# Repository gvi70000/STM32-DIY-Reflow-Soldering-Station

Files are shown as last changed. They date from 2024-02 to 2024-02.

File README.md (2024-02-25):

# STM32-DIY-Reflow-Soldering-Station

Warning: Electrical Safety Notice

Before attempting to build or operate the DIY reflow soldering station described in this article, it is imperative to be aware that the hardware operates at 220V AC. Working with high-voltage systems poses inherent risks and demands a thorough understanding of electrical safety precautions.
Front
Back

Introduction:

For electronics enthusiasts seeking a precise and customizable reflow soldering experience, constructing a DIY reflow soldering station is an exciting project. This article provides a detailed overview of the key components and their functionalities, offering a comprehensive guide for building your own soldering station.

Power Supply:

The 220V AC is supplied through the AC Power Entry Module IEC-320 C-14 BVA01/Z0000/02. A Transformer Myrra 47152 steps down the voltage to a crucial 5V, supplying power to essential components such as the BluePill with STM32F302 microcontroller board, fan, and the G3MB-202P 5V DC 1 Channel Solid-State Relay.

PowerSocket
Relay
NTC
Myrra
LCD
Plate
PEC11R-4220F-S0024
EnclosureFront
EnclosureBack
InnerView

User Interface:

The station features a user-friendly interface displayed on a 1.8" ST7735 LCD. User inputs are facilitated through an encoder PEC11R-4220F-S0024 and an RS PRO 17mm Black Potentiometer Knob for 6mm Shaft with a D-shaped grip, ensuring precise control over the soldering process.
Temperature Control and Cooling:

Maintaining optimal temperature is achieved through two strategically positioned 100K ohm 3950 NTC's, calibrated with meticulous accuracy using an FLUKE 51 II Thermometer as a reference. The reflow soldering station incorporates a CFM-6020S-040-320 fan, intelligently activated to cool down the hot plate when needed, ensuring temperature stability.

Operational Modes:

The DIY reflow soldering station offers two distinct modes: rework and reflow. In rework mode, the temperature is kept at a preset value, allowing for precise touch-up soldering. In reflow mode, the temperature follows a preset profile, ideal for soldering components with specific temperature requirements. Both modes utilize a PID controller, ensuring consistent and accurate temperature control throughout the soldering process.

Connections:

The intricate network of connections ensures seamless communication and control within the system. Notable connections include those for SD Card, Encoder, ADC for NTCs, Fan control, Hot plate power control, Buzzer, Encoder button, LCD command, and SPI interface.
Conclusion:

Building your own DIY reflow soldering station offers the satisfaction of creating a precise and reliable tool tailored to your needs. With a robust power supply, intuitive user interface, accurate temperature control, and intelligent cooling, this reflow soldering station provides the necessary features for successful soldering projects. As you embark on this DIY journey, ensure meticulous attention to detail in the assembly and follow safety guidelines to enjoy a versatile and efficient soldering tool for your electronics projects.

The enclosure outline for LASER cutting from 4mm thick acrylic sheet can be downloaded here.

KiCAD Schematic and PCB for controller are available here.

The software for STM32F302 can be downloaded here.

Please note that the PID parameters are generic and you need to change them according to your system, the values are found in Reflow.h file

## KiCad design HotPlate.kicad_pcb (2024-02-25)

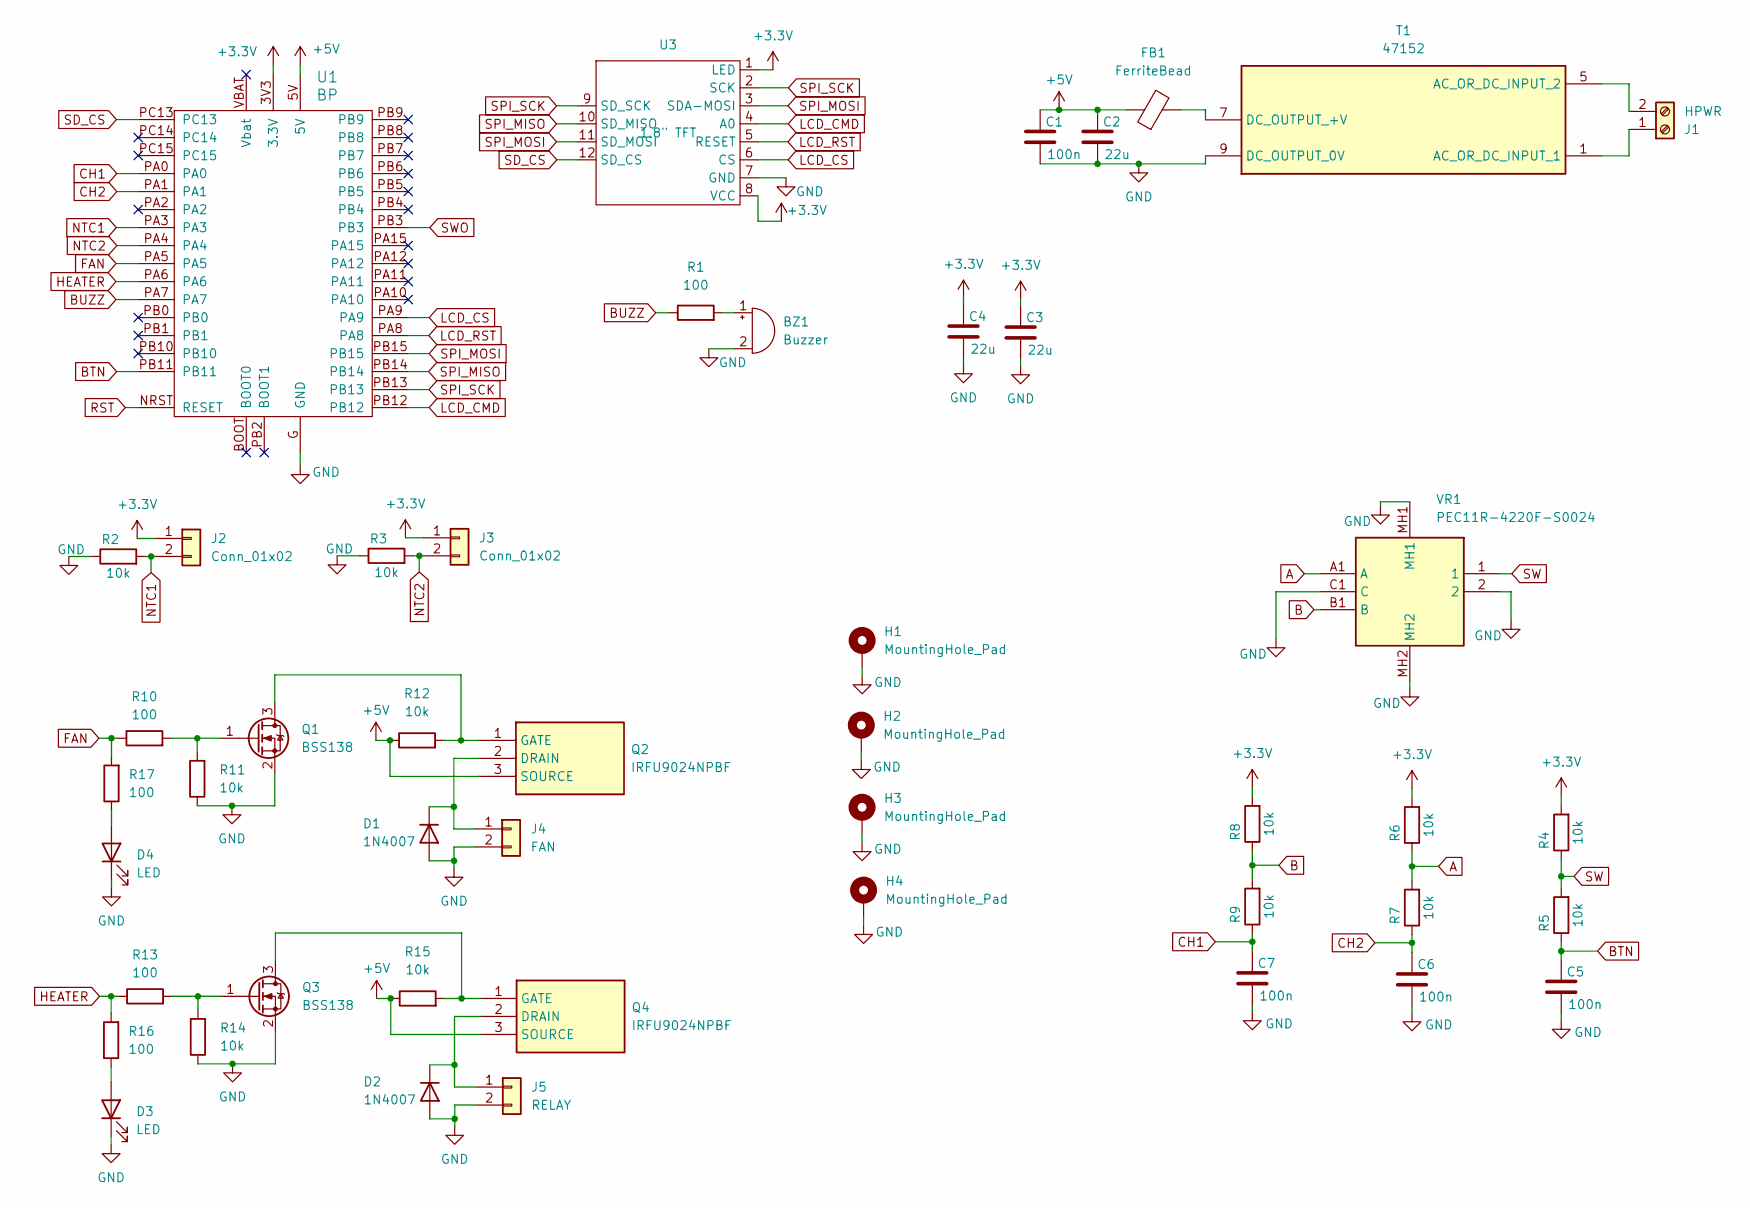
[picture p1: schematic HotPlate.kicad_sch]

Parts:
BZ1: Buzzer; Buzzer_TDK_PS1240P02BT_D12.2mm_H6.5mm
C1, C5, C6, C7: 100n; C_0805_2012Metric
C2, C3, C4: 22u; CP_EIA-7343-43_Kemet-X_Pad2.25x2.55mm_HandSolder
D1, D2: 1N4007; D_DO-41_SOD81_P10.16mm_Horizontal
D3, D4: LED; LED_D3.0mm
FB1: FerriteBead; R_0805_2012Metric
H1, H2, H3, H4: MountingHole_Pad; MountingHole_3.2mm_M3_Pad_Via
J1: HPWR; TerminalBlock_Phoenix_PT-1,5-2-5.0-H_1x02_P5.00mm_Horizontal
J2, J3: Conn_01x02; PinHeader_1x02_P2.54mm_Vertical
J4: FAN; PinHeader_1x02_P2.54mm_Vertical
J5: RELAY; PinHeader_1x02_P2.54mm_Vertical
Q1, Q3: BSS138; SOT-23
Q2, Q4: IRFU9024NPBF; TO-251-3_Vertical; Mouser Part Number 942-IRFU9024NPBF
R1: 100; R_0805_2012Metric_Pad1.20x1.40mm_HandSolder
R2, R3, R4, R5, R6, R7, R8, R9: 10k; R_0805_2012Metric_Pad1.20x1.40mm_HandSolder
R10, R13, R16, R17: 100; R_0805_2012Metric
R11, R12, R14, R15: 10k; R_0805_2012Metric
T1: 47152; MYRRA-47121; Manufacturer_Part_Number 47152
U1: BP; blue_pill
U3: 1.8" TFT; 1.8 TFT
VR1: PEC11R-4220F-S0024; PEC11R4220FS0024; Mouser Part Number 652-PEC11R-4220F-S24

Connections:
+3.3V: C3.1, C4.1, J2.1, J3.1, R4.2, R6.2, R8.2, U1.3V3 (3.3V), U3.1 (LED), U3.8 (VCC)
+5V: C1.1, C2.1, FB1.1, Q2.3 (SOURCE), Q4.3 (SOURCE), R12.1, R15.1, U1.5V
A: R6.1, R7.2, VR1.A1 (A)
B: R8.1, R9.2, VR1.B1 (B)
BTN: C5.1, R5.1, U1.PB11
BUZZ: R1.1, U1.PA7
CH1: C7.1, R9.1, U1.PA0
CH2: C6.1, R7.1, U1.PA1
FAN: R10.1, R17.2, U1.PA5
GND: BZ1.2 (+), C1.2, C2.2, C3.2, C4.2, C5.2, C6.2, C7.2, D1.2 (A), D2.2 (A), D3.1 (K), D4.1 (K), H1.1, H2.1, H3.1, H4.1, J4.2, J5.2, Q1.2 (S), Q3.2 (S), R2.1, R3.1, R11.1, R14.1, T1.9 (DC_OUTPUT_0V), U1.G (GND), U3.7 (GND), VR1.2, VR1.C1 (C), VR1.MH1, VR1.MH2
HEATER: R13.1, R16.2, U1.PA6
LCD_CMD: U1.PB12, U3.4 (A0)
LCD_CS: U1.PA9, U3.6 (CS)
LCD_RST: U1.PA8, U3.5 (RESET)
NTC1: J2.2, R2.2, U1.PA3
NTC2: J3.2, R3.2, U1.PA4
unnamed: BZ1.1 (-), R1.2
unnamed: D1.1 (K), J4.1, Q2.2 (DRAIN)
unnamed: D2.1 (K), J5.1, Q4.2 (DRAIN)
unnamed: D3.2 (A), R16.1
unnamed: D4.2 (A), R17.1
unnamed: J1.1, T1.1 (AC_OR_DC_INPUT_1)
unnamed: J1.2, T1.5 (AC_OR_DC_INPUT_2)
unnamed: Q1.3 (D), Q2.1 (GATE), R12.2
unnamed: Q1.1 (G), R10.2, R11.2
unnamed: Q3.3 (D), Q4.1 (GATE), R15.2
unnamed: Q3.1 (G), R13.2, R14.2
unnamed: FB1.2, T1.7 (DC_OUTPUT_+V)
RST: U1.NRST (RESET)
SD_CS: U1.PC13, U3.12 (SD_CS)
SPI_MISO: U1.PB14, U3.10 (SD_MISO)
SPI_MOSI: U1.PB15, U3.3 (SDA-MOSI), U3.11 (SD_MOSI)
SPI_SCK: U1.PB13, U3.2 (SCK), U3.9 (SD_SCK)
SW: R4.1, R5.2, VR1.1
SWO: U1.PB3

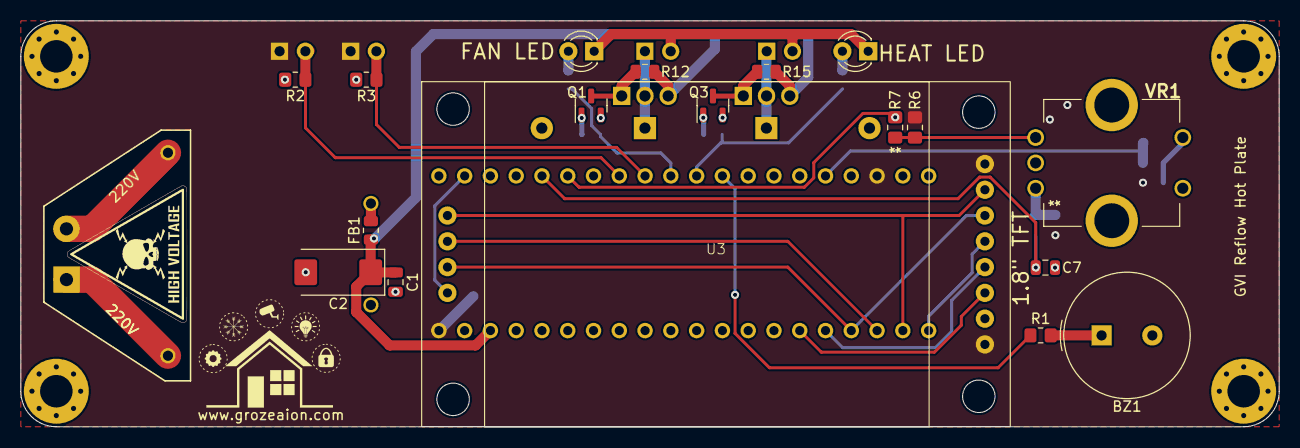
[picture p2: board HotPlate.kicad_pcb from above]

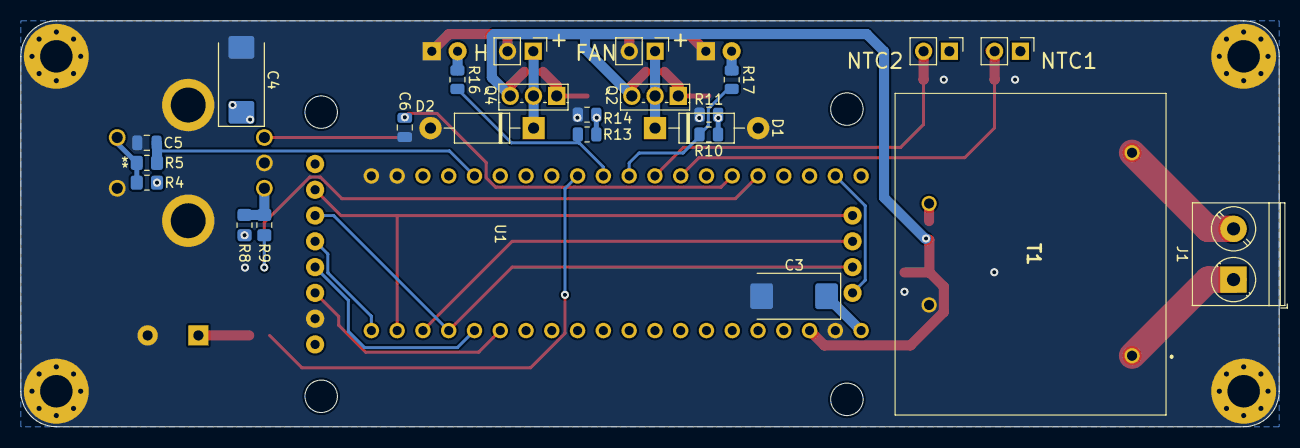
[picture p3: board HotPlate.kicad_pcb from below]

Board: 2 copper layers, 124.0 x 40.0 mm, 47 parts (25 on the bottom side), 33 nets.

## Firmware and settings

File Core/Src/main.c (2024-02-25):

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
/* Includes ------------------------------------------------------------------*/
#include "main.h"
#include "adc.h"
#include "dma.h"
#include "spi.h"
#include "tim.h"
#include "gpio.h"

/* USER CODE BEGIN Includes */
#include "Reflow.h"
#include "ST7735.h"
#include <stdio.h>
/* USER CODE END Includes */


/* USER CODE BEGIN PV */
extern volatile uint8_t BtnPressed;
extern volatile float crtTemp;
const uint8_t encoderPeriod = 50; // Read the encoder keys every 50ms
uint32_t encTime;
#ifdef AUTOTUNE
	extern float autotuneSetpoint;
#endif	
/* USER CODE END PV */

void SystemClock_Config(void);
/* USER CODE BEGIN PFP */
void drawMenu(uint8_t menuIdx);
void Menu_Main();
void Menu_Rework();
void changeValue();
void refreshMenu();
/* USER CODE END PFP */

/**
  * @brief  The application entry point.
  * @retval int
  */
int main(void)
{
  /* MCU Configuration--------------------------------------------------------*/

  /* Reset of all peripherals, Initializes the Flash interface and the Systick. */
  HAL_Init();

  /* Configure the system clock */
  SystemClock_Config();

  /* Initialize all configured peripherals */
  MX_GPIO_Init();
  MX_DMA_Init();
  MX_SPI2_Init();
  MX_TIM2_Init();
  MX_ADC1_Init();
  MX_ADC2_Init();
  MX_TIM1_Init();
  MX_TIM4_Init();
  /* USER CODE BEGIN 2 */
	// Start LCD
	ST7735_Unselect;
	ST7735_Init(1);
	fillScreen(BLACK);
	//Start Encoder timer
	HAL_TIM_Encoder_Start_IT(&htim2, TIM_CHANNEL_ALL);
	// Set Buzzer duty cycle
	htim1.Instance->CCR1 = 250;//Duty Cycle%*20
	// Draw the Main menu
	
	#ifdef AUTOTUNE
		// START ADC to be able to get the temperature
		startADC();
		// This is the target temperature to tune PID parameters
		autotuneSetpoint = 50.0;
	#else
		Menu_Main();
	#endif
	
  /* USER CODE END 2 */

  /* Infinite loop */
  /* USER CODE BEGIN WHILE */
  while (1)
  {
		#ifdef AUTOTUNE
			// Perform PID autotuning
			autotunePID();
			// Perform temperature control using PID parameters
			TemperatureControl(autotuneSetpoint);
		#else
			Navigation();
		#endif
    /* USER CODE END WHILE */

    /* USER CODE BEGIN 3 */
  }
  /* USER CODE END 3 */
}

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


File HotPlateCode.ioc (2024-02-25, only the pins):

Mcu.UserName=STM32F302CCTx
PA0.Signal=S_TIM2_CH1_ETR
PA1.Signal=S_TIM2_CH2
PA13.Signal=SYS_JTMS-SWDIO
PA14.Signal=SYS_JTCK-SWCLK
PA3.GPIO_Label=NTC1
PA3.Signal=ADC1_IN4
PA4.GPIO_Label=NTC2
PA4.Signal=ADC2_IN1
PA5.GPIO_Label=FAN
PA5.Signal=GPIO_Output
PA6.GPIO_Label=HEATER
PA6.Signal=GPIO_Output
PA7.Signal=TIM1_CH1N
PA8.GPIO_Label=LCD_RST
PA8.Signal=GPIO_Output
PA9.GPIO_Label=LCD_CS
PA9.Signal=GPIO_Output
PB11.GPIO_Label=BTN
PB11.Signal=GPXTI11
PB12.GPIO_Label=LCD_CMD
PB12.Signal=GPIO_Output
PB13.Signal=SPI2_SCK
PB14.Signal=SPI2_MISO
PB15.Signal=SPI2_MOSI
PB3.Signal=SYS_JTDO-TRACESWO
PC13.Signal=GPIO_Output
PF0-OSC_IN.Signal=RCC_OSC_IN
PF1-OSC_OUT.Signal=RCC_OSC_OUT

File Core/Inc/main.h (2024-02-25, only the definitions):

#define NTC1_Pin GPIO_PIN_3
#define NTC1_GPIO_Port GPIOA
#define NTC2_Pin GPIO_PIN_4
#define NTC2_GPIO_Port GPIOA
#define FAN_Pin GPIO_PIN_5
#define FAN_GPIO_Port GPIOA
#define HEATER_Pin GPIO_PIN_6
#define HEATER_GPIO_Port GPIOA
#define BTN_Pin GPIO_PIN_11
#define BTN_GPIO_Port GPIOB
#define BTN_EXTI_IRQn EXTI15_10_IRQn
#define LCD_CMD_Pin GPIO_PIN_12
#define LCD_CMD_GPIO_Port GPIOB
#define LCD_RST_Pin GPIO_PIN_8
#define LCD_RST_GPIO_Port GPIOA
#define LCD_CS_Pin GPIO_PIN_9
#define LCD_CS_GPIO_Port GPIOA

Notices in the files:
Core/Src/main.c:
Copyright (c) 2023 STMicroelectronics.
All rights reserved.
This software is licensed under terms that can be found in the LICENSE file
